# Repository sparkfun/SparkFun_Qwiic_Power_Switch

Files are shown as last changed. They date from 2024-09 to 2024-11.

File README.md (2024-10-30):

SparkFun Qwiic Power Switch
========================================

A power switch for your Qwiic system.

SparkFun Qwiic Power Switch (PRT-26784) (https://www.sparkfun.com/products/26784)

[SparkFun Qwiic Power Switch (PRT-26784)](https://www.sparkfun.com/products/26784)

The Qwiic Power Switch is a simple little board which can be used to switch the power to your Qwiic
system. Many Qwiic boards draw very little current when not being used, but there are some that draw
significantly more. The power switch allows you to switch the power to those boards, so you can minimize the
current draw and extend your battery life when you need to.

When the Qwiic Power Switch is turned off, the I2C wires are isolated too which prevents the pull-up
resistors from feeding parasitic power to your Qwiic boards. The power switch can also be used to
isolate a 400kHz bus from a 100kHz bus; the slower bus can be disconnected during fast-mode communication
without disabling the power.

The heart of the Qwiic Power Switch is the TI PCA9536 4-Bit I2C I/O Expander. We have broken out GPIO pins
1 and 2 so you can use them as general purpose inputs or outputs.

Repository Contents
-------------------

* **.github/workflows** - YAML files used for GitHub Actions and GitHub Pages/mkdocs
* **/Hardware** - Eagle design files (.brd, .sch)
  * **/Production** - Production panel files (.brd)
* **/docs** - Online documentation files
  * **/assets** - Folder containing all the file assets used for product documentation
    * **/board_files** - Copy of design files used for product documentation
    * **/component_documentation** - Datasheets and manuals for hardware components
    * **/img** - Images for product documentation
  * **/github** - Files stating how to contribute and filing issues used for product documentation
  * **/javascript** - Folder containing custom javascript used for product documentation
  * **/stylesheet** - Folder containing CSS files used for product documentation
* **/overrides** - Customization files used for product documentation
  * **/.icons** - Icons used for GitHub used for product documentation
  * **./partials** - Used for product documentation
* **LICENSE.md** contains the licence information

Documentation
-------------------

* **[Installing an Arduino Library Guide](https://learn.sparkfun.com/tutorials/installing-an-arduino-library)** - Basic information on how to install an Arduino library.
* **[Arduino Library](https://github.com/sparkfun/SparkFun_Qwiic_Power_Switch_Arduino_Library)** - Library for the Qwiic Power Switch
* **[Hookup Guide](https://docs.sparkfun.com/SparkFun_Qwiic_Power_Switch/introduction/)** - Basic hookup guide for the Qwiic Power Switch.

Product Versions
----------------

* [PRT-26784](https://www.sparkfun.com/products/26784) - SparkFun Red Version
* [SPX-16740](https://www.sparkfun.com/products/16740) - SparkX Version

License Information
-------------------

This product is _**open source**_!

Please review the LICENSE.md file for license information.

If you have any questions or concerns on licensing, please contact technical support on our [SparkFun forums](https://forum.sparkfun.com/viewforum.php?f=123).

Distributed as-is; no warranty is given.

- Your friends at SparkFun.

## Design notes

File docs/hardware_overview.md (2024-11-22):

In this section, we will highlight the hardware and pins that are broken out on the SparkFun Qwiic Power Switch. For more information, check out our [Resources and Going Further](../resources/) on the components used on the breakout board.

<div style="text-align: center;">
  <table>
    <tr style="vertical-align:middle;">
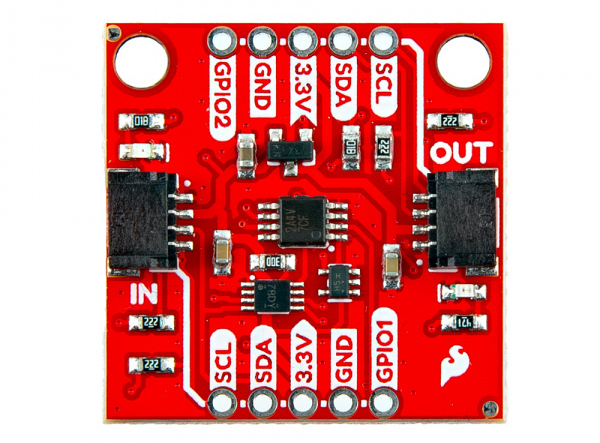
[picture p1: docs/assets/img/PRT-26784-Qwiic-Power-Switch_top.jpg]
Top View
     <td style="text-align: center; vertical-align: middle; border: solid 1px #cccccc;"></td>
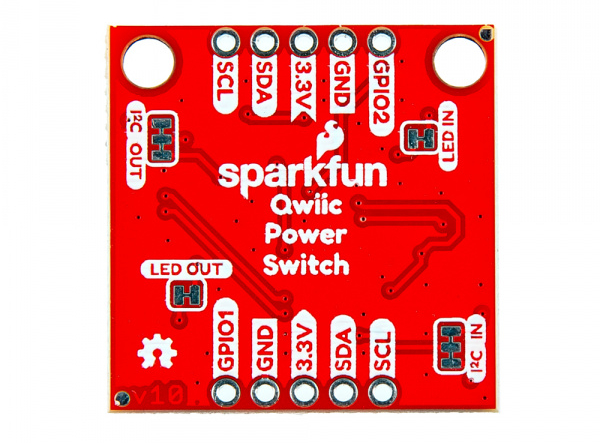
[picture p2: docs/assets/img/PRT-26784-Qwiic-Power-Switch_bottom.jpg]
Bottom View
     <td style="text-align: center; vertical-align: middle; border: solid 1px #cccccc;"></td>
    </tr>
    <tr style="vertical-align:middle;">
     <td style="text-align: center; vertical-align: middle; border: solid 1px #cccccc;"><i>Top View</i></td>
     <td style="text-align: center; vertical-align: middle; border: solid 1px #cccccc;"><i>Bottom View</i></td>
    </tr>
  </table>
</div>

### Power

To power the board, we recommend applying 3.3V to the 3.3V pin on the side labeled IN. While the IC's operating voltage is 2.3V to 5.5V, we recommend limiting the input voltage to 3.3V for the Qwiic Connect System. Below are the power pins that are broken out on the edge of the board.

* **IN - 3.3V** &mdash; This pin is the voltage input for the board. The recommended input voltage for this pin is 3.3V.
* **OUT - 3.3V** &mdash; This pin is the voltage output for the board. When the PCA9536 GPIO0 enables the transistor, any Qwiic enabled device that is connected to this side of the board will be powered by 3.3V.
* **GND** &mdash; Of course, is the common, ground voltage (0V reference) for the system.

<div style="text-align: center;">
  <table>
    <tr style="vertical-align:middle;">
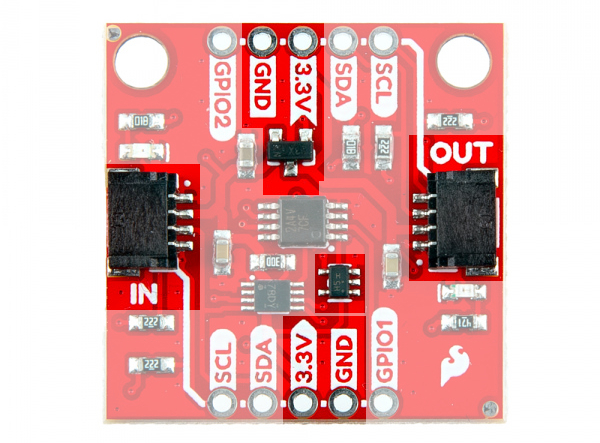
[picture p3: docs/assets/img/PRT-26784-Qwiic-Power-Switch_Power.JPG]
Power, Ground, Transistor and Qwiic Connector Highlighted
     <td style="text-align: center; vertical-align: middle; border: solid 1px #cccccc;"></td>
    </tr>
    <tr style="vertical-align:middle;">
     <td style="text-align: center; vertical-align: middle; border: solid 1px #cccccc;"><i>Power, Ground, Transistor, and Qwiic Connector Highlighted</i></td>
    </tr>
  </table>
</div>

### Qwiic and I<sup>2</sup>C

The board includes two horizontal Qwiic connectors to connect Qwiic-enabled I<sup>2</sup>C devices. However, the board still breaks out 0.1"-spaced pins for users who prefer a soldered connection. The PCA9306 dual bidirectional I<sup>2</sup>C bus voltage level translator (the 8-pin IC closer to IN by the SDA and 3.3V PTHs) is included between the input and output Qwiic connectors. This acts as a bus isolator between the input and output pins for the data and clock lines. This prevents the pull-up resistors from feeding parasitic power to your Qwiic-enabled boards. The Qwiic Power Switch can also be used to isolate a 400kHz bus from a 100kHz bus; the slower bus on the output of the Qwiic Power Switch can be disconnected during fast-mode communication without disabling power.

* **IN**
    * **SCL** &mdash; I<sup>2</sup>C clock on the PCA9306&apos;s input side.
    * **SDA** &mdash; I<sup>2</sup>C data on the PCA9306&apos;s input side.
    * **3.3V** &mdash; This pin is the voltage input for the board. The recommended input voltage for this pin is 3.3V.
* **OUT**
    * **SCL** &mdash; I<sup>2</sup>C clock on the PCA9306&apos;s output side.
    * **SDA** &mdash; I<sup>2</sup>C data on the PCA9306&apos;s output side.
    * **3.3V** &mdash; This pin is the voltage output for the board. When the PCA9536 GPIO0 enables the transistor, any Qwiic enabled device that is connected to this side of the board will be powered by 3.3V.
* **GND** &mdash; Of course, is the common, ground voltage (0V reference) for the system. The GND PTHs are connected to both IN and OUT.

<div style="text-align: center;">
  <table>
    <tr style="vertical-align:middle;">
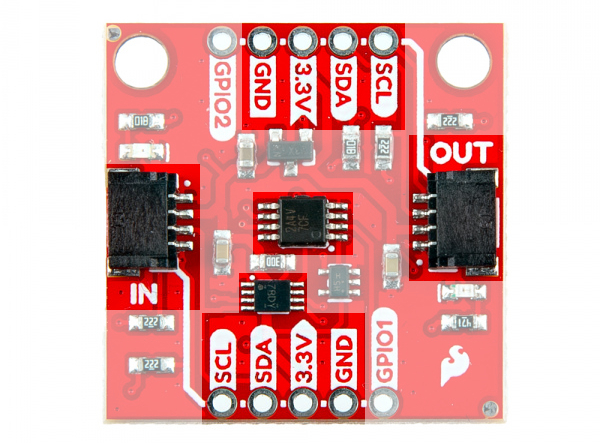
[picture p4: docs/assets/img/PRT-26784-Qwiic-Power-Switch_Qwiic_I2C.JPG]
Qwiic Connector, I2C, and PCA9306 Highlighted
     <td style="text-align: center; vertical-align: middle; border: solid 1px #cccccc;"></td>
    </tr>
    <tr style="vertical-align:middle;">
     <td style="text-align: center; vertical-align: middle; border: solid 1px #cccccc;"><i>Qwiic Connector, I<sup>2</sup>C, and PCA9306 Highlighted</i></td>
    </tr>
  </table>
</div>

Connected on the input I<sup>2</sup>C bus is the TI PCA9536 4-Bit I<sup>2</sup>C I/O Expander (the bigger 8-pin IC located at the center of the board). This IC is used to toggle output 3.3V power and the PCA9306 I<sup>2</sup>C isolation. Its I<sup>2</sup>C device's 7-bit unshifted address is **0x41**.

### PCA9536 and GPIO Pins

The PCA9536 is a 4-bit GPIO IC that enables users to toggle the following GPIO pins through I<sup>2</sup>C. The I<sup>2</sup>C address of the PCA9536 is **0x41**.

* **GPIO0** &mdash; GPIO0 is connected to the MOSFET power switch. This controls the voltage between the 3.3V input pin and VOUT. When this transistor is turned off, power is removed from the I<sup>2</sup>C output's pull-up resistors.
* **GPIO1** &mdash; GPIO1 is an extra GPIO pin.
* **GPIO2** &mdash; GPIO2 is an extra GPIO pin.
* **GPIO3** &mdash; This pin is connected to the PCA9306. This allows you to isolate the I<sup>2</sup>C output.

<div style="text-align: center;">
  <table>
    <tr style="vertical-align:middle;">
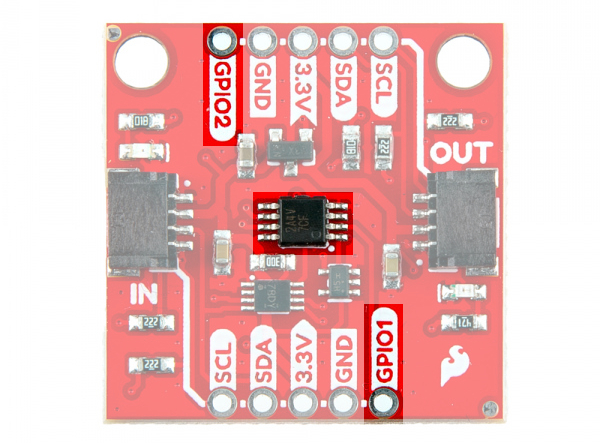
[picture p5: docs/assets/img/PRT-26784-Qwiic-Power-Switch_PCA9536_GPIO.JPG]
PCA9536 and GPIO Pins Highlighted
     <td style="text-align: center; vertical-align: middle; border: solid 1px #cccccc;"></td>
    </tr>
    <tr style="vertical-align:middle;">
     <td style="text-align: center; vertical-align: middle; border: solid 1px #cccccc;"><i>PCA9536 and GPIO Pins Highlighted</i></td>
    </tr>
  </table>
</div>

### LEDs

The board includes two LEDs to indicate when power is available on the input and output's 3.3V pins. Both can be disabled with the jumpers on the back of the board.

<div style="text-align: center;">
  <table>
    <tr style="vertical-align:middle;">
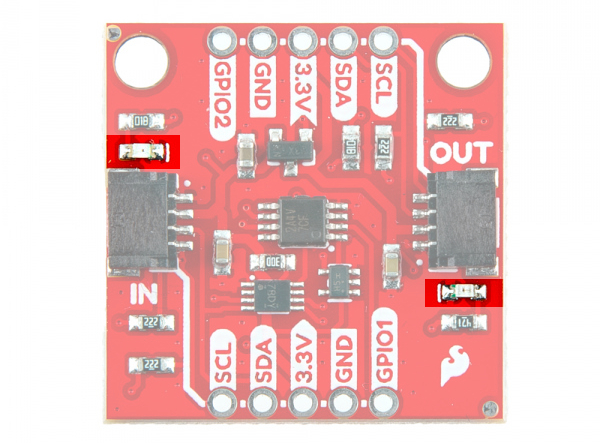
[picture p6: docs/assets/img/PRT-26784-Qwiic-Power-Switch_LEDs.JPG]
LEDs Highlighted
     <td style="text-align: center; vertical-align: middle; border: solid 1px #cccccc;"></td>
    </tr>
    <tr style="vertical-align:middle;">
     <td style="text-align: center; vertical-align: middle; border: solid 1px #cccccc;"><i>LEDs Highlighted</i></td>
    </tr>
  </table>
</div>

### Jumpers

!!!note
    If this is your first time working with jumpers, check out the [How to Work with Jumper Pads and PCB Traces](https://learn.sparkfun.com/tutorials/how-to-work-with-jumper-pads-and-pcb-traces/all) tutorial for more information.

The back of the board includes jumpers to configure the board.

* **I<sup>2</sup>C IN** &mdash; By default, this three-pad jumper is closed. The three way jumper labeled I<sup>2</sup>C IN connects 3.3V to two 2.2k&ohm; pull-up resistors and to the I<sup>2</sup>C data and clock lines. If multiple devices are connected to the bus with the pull-up resistors enabled, the parallel equivalent resistance will create too strong of a pull-up for the bus to operate correctly. As a general rule of thumb, [disable all but one pair of pull-up resistors](https://learn.sparkfun.com/tutorials/i2c/all#i2c-at-the-hardware-level) if multiple devices are connected to the bus.
* **I<sup>2</sup>C OUT** &mdash; By default, this three-pad jumper is closed. Similar to the I<sup>2</sup>C IN jumper, this jumper is connects the VOUT net to two 2.2k&ohm; pull-up resistors and to the I<sup>2</sup>C data and clock lines. This VOUT is controlled by a MOSFET power switch and PCA9536's GPIO0. When the transistor is turned on, VOUT will connect to the input 3.3V pin.
* **LED IN** &mdash; By default, this jumper connects the LED to the input's 3.3V pin. Cutting this trace disables the LED.
* **LED OUT** &mdash; By default, this jumper connects the LED to the output's 3.3V pin. Cutting this trace disables the LED.

<div style="text-align: center;">
  <table>
    <tr style="vertical-align:middle;">
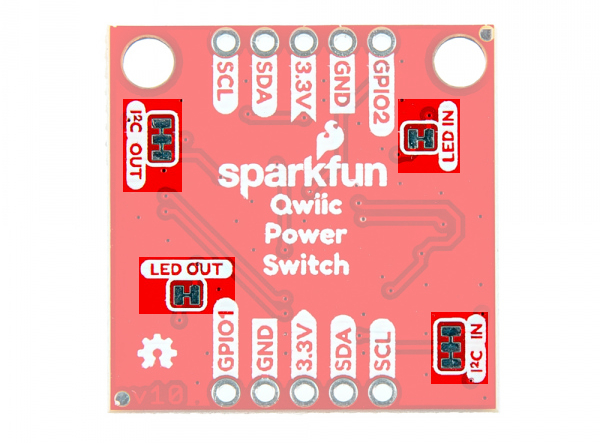
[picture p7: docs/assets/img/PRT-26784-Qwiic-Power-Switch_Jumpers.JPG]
Jumpers Highlighted
     <td style="text-align: center; vertical-align: middle; border: solid 1px #cccccc;"></td>
    </tr>
    <tr style="vertical-align:middle;">
     <td style="text-align: center; vertical-align: middle; border: solid 1px #cccccc;"><i>Jumpers Highlighted</i></td>
    </tr>
  </table>
</div>

### Board Dimensions

The board is 1.0" x 1.0" (25.4mm x 25.4mm). There are 2x mounting holes. You can use 4-40 standoffs to mount the board to a panel or enclosure.

<div style="text-align: center;">
  <table>
    <tr style="vertical-align:middle;">
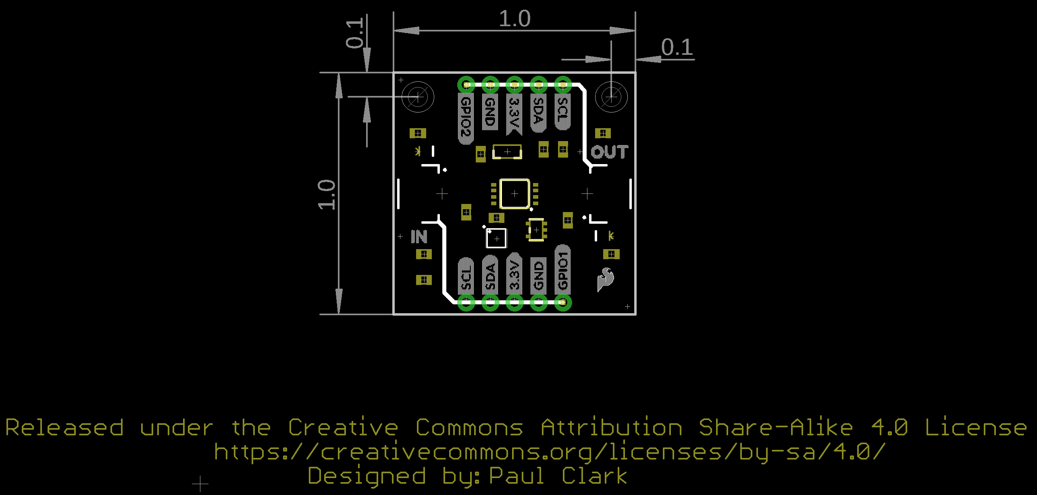
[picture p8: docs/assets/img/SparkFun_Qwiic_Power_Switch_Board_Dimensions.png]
Board Dimensions
     <td style="text-align: center; vertical-align: middle; border: solid 1px #cccccc;"></td>
    </tr>
    <tr style="vertical-align:middle;">
     <td style="text-align: center; vertical-align: middle; border: solid 1px #cccccc;"><i>Board Dimensions</i></td>
    </tr>
  </table>
</div>

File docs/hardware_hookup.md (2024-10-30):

In this section, we will go over how to connect to the Qwiic Power Switch.

### Connecting Via Qwiic

Insert a Qwiic cable between your Arduino microcontroller and the Qwiic Power Switch&apos;s IN port. In this case, we used the SparkFun Thing Plus ESP32- USB-C for the Arduino microcontroller. Then connect Qwiic cable between the Qwiic Power Switch's OUT port to the second Qwiic-enabled device. In this case, we used the ZED-F9P SMA breakout board when toggling power and isolating the I<sup>2</sup>C lines. We also connected an external multiband antenna to the ZED-F9P. When ready, connect a USB cable to the Arduino to program, power, and control the Qwiic Power Switch through a serial terminal.

<div style="text-align: center;">
  <table>
    <tr style="vertical-align:middle;">
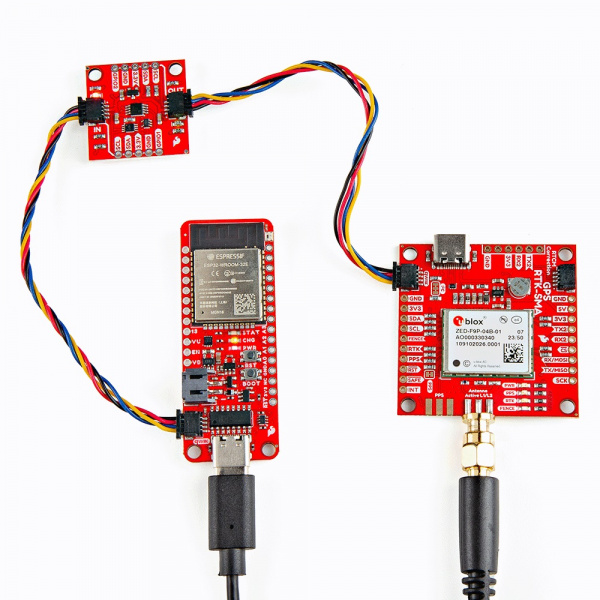
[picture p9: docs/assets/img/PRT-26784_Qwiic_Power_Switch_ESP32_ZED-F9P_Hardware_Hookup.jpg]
Thing Plus ESP32, Qwiic Power Switch, ZED-F9P Connected via Qwiic
     <td style="text-align: center; vertical-align: middle; border: solid 1px #cccccc;"></td>
    </tr>
    <tr style="vertical-align:middle;">
     <td style="text-align: center; vertical-align: middle; border: solid 1px #cccccc;"><i>Thing Plus ESP32, Qwiic Power Switch, ZED-F9P Connected via Qwiic</i></td>
    </tr>
  </table>
</div>

!!! note
    To isolate any Qwiic-enabled device, you will need to connect the Qwiic-enabled device from the OUT port.

### Connecting via PTH

For temporary connections to the PTHs, you could use IC hooks to test out the pins. However, you'll need to solder headers or wires of your choice to the board for a secure connection. You can choose between a combination of [header pins and jumper wires](https://learn.sparkfun.com/tutorials/how-to-solder-through-hole-soldering/all), or [stripping wire and soldering the wire](https://learn.sparkfun.com/tutorials/working-with-wire/all) directly to the board.

<div class="grid cards col-2" markdown>

-   <a href="https://learn.sparkfun.com/tutorials/how-to-solder-through-hole-soldering/all">
      <figure markdown>
        How to Solder: Through Hole Soldering
      </figure>
    </a>

    ---

    <a href="https://learn.sparkfun.com/tutorials/how-to-solder-through-hole-soldering/all">
      <b>How to Solder: Through Hole Soldering</b>
    </a>
<!-- ----------WHITE SPACE BETWEEN GRID CARDS---------- -->

-   <a href="https://learn.sparkfun.com/tutorials/working-with-wire/all">
      <figure markdown>
        Working with Wire
      </figure>
    </a>

    ---

    <a href="https://learn.sparkfun.com/tutorials/working-with-wire/all">
      <b>Working with Wire</b>
    </a>
<!-- ----------WHITE SPACE BETWEEN GRID CARDS---------- -->
</div>

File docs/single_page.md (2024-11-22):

---
hide:
  - navigation
  - toc
icon: fontawesome/solid/scroll
---

# Introduction
--8<-- "./docs/introduction.md"

# Hardware Overview
--8<-- "./docs/hardware_overview.md"

# Hardware Hookup
--8<-- "./docs/hardware_hookup.md"

# Setting Up Arduino
--8<-- "./docs/arduino_library.md"

# Arduino Example
--8<-- "./docs/arduino_example.md"

# Troubleshooting
--8<-- "./docs/troubleshooting.md"

# Resources
--8<-- "./docs/resources.md"

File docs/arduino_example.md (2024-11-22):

Now that we have our library and board add-on installed, we can start experimenting with the breakout board. For the scope of this tutorial, we will highlight the example in the Arduino Library to get started.

### Upload Arduino Example

After unzipping the compressed files, navigate to the example: **File** > **Examples** > **SparkFun Qwiic Power Switch Arduino Library** > **Example1_PowerOnOff**. This example allows you to toggle power and isolate the I<sup>2</sup>C lines for the OUT port through a serial terminal. The example also allows you to read GPIO1 and GPIO2.

For users using an Arduino microcontroller, select your board in the Tools menu (in our case the **SparkFun ESP32 Thing Plus C**) and the correct Port it enumerated on.

You can also copy or paste the code as shown below. Then click "Upload".

``` c++
    /*
      Using the Qwiic Power Switch
      By: Paul Clark (PaulZC)
      Date: April 23rd, 2020

      Based extensively on:
      Using the PCA9536 -- Digital Output
      By: Jim Lindblom
      SparkFun Electronics
      Date: May 4, 2018

      License: This code is public domain but you buy me a beer if you use this and we meet someday (Beerware license).

      This example demonstrates how to use the Qwiic Power Switch and read the additional GPIO pins

      Hardware Connections:
      Attach your Arduino to the Qwiic Power Switch IN
      Plug your Qwiic device into the Qwiic Power Switch OUT
      https://www.sparkfun.com/products/15081
    */

    #include <Wire.h>

    #include <SparkFun_Qwiic_Power_Switch_Arduino_Library.h>

    QWIIC_POWER mySwitch;

    void setup(void)
    {
      Serial.begin(115200);
      while (!Serial)
        ; //Wait for user to open terminal
      Serial.println(F("Qwiic Power Switch Example"));

      Wire.begin();

      if (mySwitch.begin() == false) //Connect to the power switch using Wire port
      {
        Serial.println(F("Qwiic Power Switch not detected at default I2C address. Please check wiring. Freezing."));
        while (1)
          ;
      }

      // Configure GPIO1 and GPIO2 as INPUT
      mySwitch.pinMode(1, INPUT);
      mySwitch.pinMode(2, INPUT);

      Serial.println(F("1) Enable power and I2C"));
      Serial.println(F("2) Disable power and I2C"));
      Serial.println(F("3) Enable I2C isolation"));
      Serial.println(F("4) Disable I2C isolation"));
    }

    void loop()
    {
      if (Serial.available())
      {
        byte incoming = Serial.read();

        if (incoming == '1')
        {
          // Switch the power on
          mySwitch.powerOn();
          Serial.println(F("Power is ON. I2C isolation is disabled."));
        }
        else if (incoming == '2')
        {
          // Switch the power off
          mySwitch.powerOff();
          Serial.println(F("Power is OFF. I2C isolation is enabled."));
        }
        else if (incoming == '3')
        {
          // Enable I2C isolation = I2C bus _is_ isolated
          mySwitch.isolationOn();
          Serial.println(F("I2C isolation enabled. I2C is isolated."));
        }
        else if (incoming == '4')
        {
          // Disable I2C isolation = I2C bus _is not_ isolated
          mySwitch.isolationOff();
          Serial.println(F("I2C isolation disabled. I2C is not isolated."));
        }

        // Read and print the GPIO1/GPIO2 state
        Serial.print(F("GPIO1 is: "));
        Serial.println(mySwitch.digitalRead(1));
        Serial.print(F("GPIO2 is: "));
        Serial.println(mySwitch.digitalRead(2));

        // Read any extra Serial bytes (e.g. CR or LF)
        while (Serial.available() > 0)
        {
          Serial.read();
        }
      }
    }

```

!!! tip
    Instead of reading GPIO1 and GPIO2, you can write to the GPIO pins to set the pins HIGH or LOW. You will need to change the following lines of code in the `setup()` and `loop()` functions where the GPIO1 and GPIO2 are initialized and read.

    ``` c++
    setup(){
      .
      .
      .
      // Configure GPIO1 and GPIO2 as INPUT
      mySwitch.pinMode(1, INPUT);
      mySwitch.pinMode(2, INPUT);
      .
      .
      .
    }

    void loop() {
          .
          .
          .
          // Read and print the GPIO1/GPIO2 state
          Serial.print(F("GPIO1 is: "));
          Serial.println(mySwitch.digitalRead(1));
          Serial.print(F("GPIO2 is: "));
          Serial.println(mySwitch.digitalRead(2));
          .
          .
          .
    }
    ```

    Instead of an INPUT, you will change each GPIO pin as an OUTPUT. Additionally, you will need to set the pin as a HIGH or LOW.

    ``` c++
    setup(){
      .
      .
      .
      // Configure GPIO1 and GPIO2 as OUTPUT
      mySwitch.pinMode(1, OUTPUT);
      mySwitch.pinMode(2, OUTPUT);
      .
      .
      .
    }

    void loop() {
          .
          .
          .
          // Write to GPIO1 & GPIO2
          Serial.println(F("GPIO1 is set to HIGH."));
          mySwitch.digitalWrite(1, HIGH);
          Serial.println(F("GPIO2 is set to LOW."));
          mySwitch.digitalWrite(2, LOW);
          .
          .
          .
    }
    ```

    To test, simply attach an LED with a current limiting resistor between the GPIO and GND. The LED should light up when the pin is HIGH and turn off when set to LOW. Of course, you can also connect a multimeter set to read the voltage between the GPIO pin nd GND. The GPIO pin should read 3.3V when set to HIGH and 0V when set to LOW.

After uploading the code, open the [Serial Monitor](https://learn.sparkfun.com/tutorials/terminal-basics) or terminal emulator of your choice with the baud rate set to **115200**. You will be presented with a few options to configure the Qwiic Power Switch:

* <kbd>1</kbd> &mdash; Power is ON I2C isolation is disabled.
* <kbd>2</kbd> &mdash; Power is OFF. I2C isolation is enabled.
* <kbd>3</kbd> &mdash; I2C isolation enabled. I2C is isolated.
* <kbd>4</kbd> &mdash; I2C isolation disabled. I2C is not isolated.

<div style="text-align: center;">
  <table>
    <tr style="vertical-align:middle;">
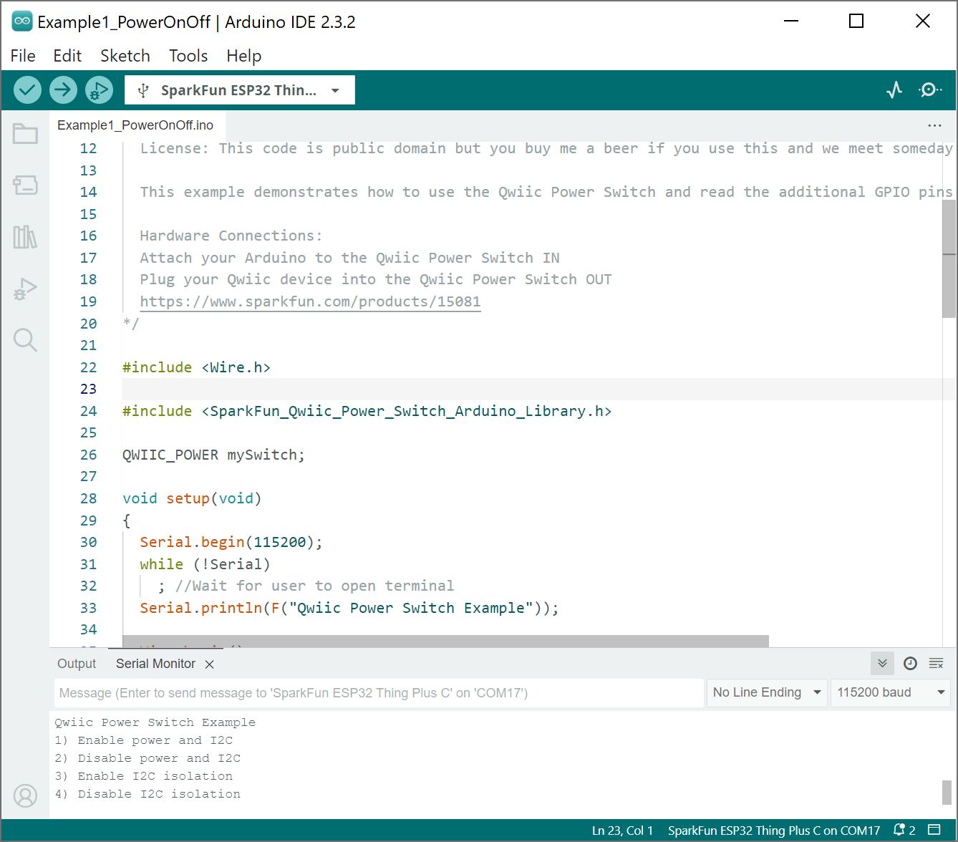
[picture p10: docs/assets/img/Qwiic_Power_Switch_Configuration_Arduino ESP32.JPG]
Qwiic Power Switch Configuration with Arduino ESP32
     <td style="text-align: center; vertical-align: middle; border: solid 1px #cccccc;"></td>
    </tr>
    <tr style="vertical-align:middle;">
     <td style="text-align: center; vertical-align: middle; border: solid 1px #cccccc;"><i>Qwiic Power Switch Configuration with Arduino ESP32</i></td>
    </tr>
  </table>
</div>

Let&apos;s send a <kbd>2</kbd> to turn power off the Qwiic Power Switch&apos;s output and isolate the I<sup>2</sup>C data and clock lines. The Arduino will output a message: "Power is OFF. I2C isolation is enabled." The Arduino will also read the Qwiic Power Switch's GPIO1 and GPIO2. In this case, there was nothing connected to either GPIO so the pin reading was `1` indicating a HIGH. If there was a logic LOW, the pin would read `0` indicating a LOW.

<div style="text-align: center;">
  <table>
    <tr style="vertical-align:middle;">
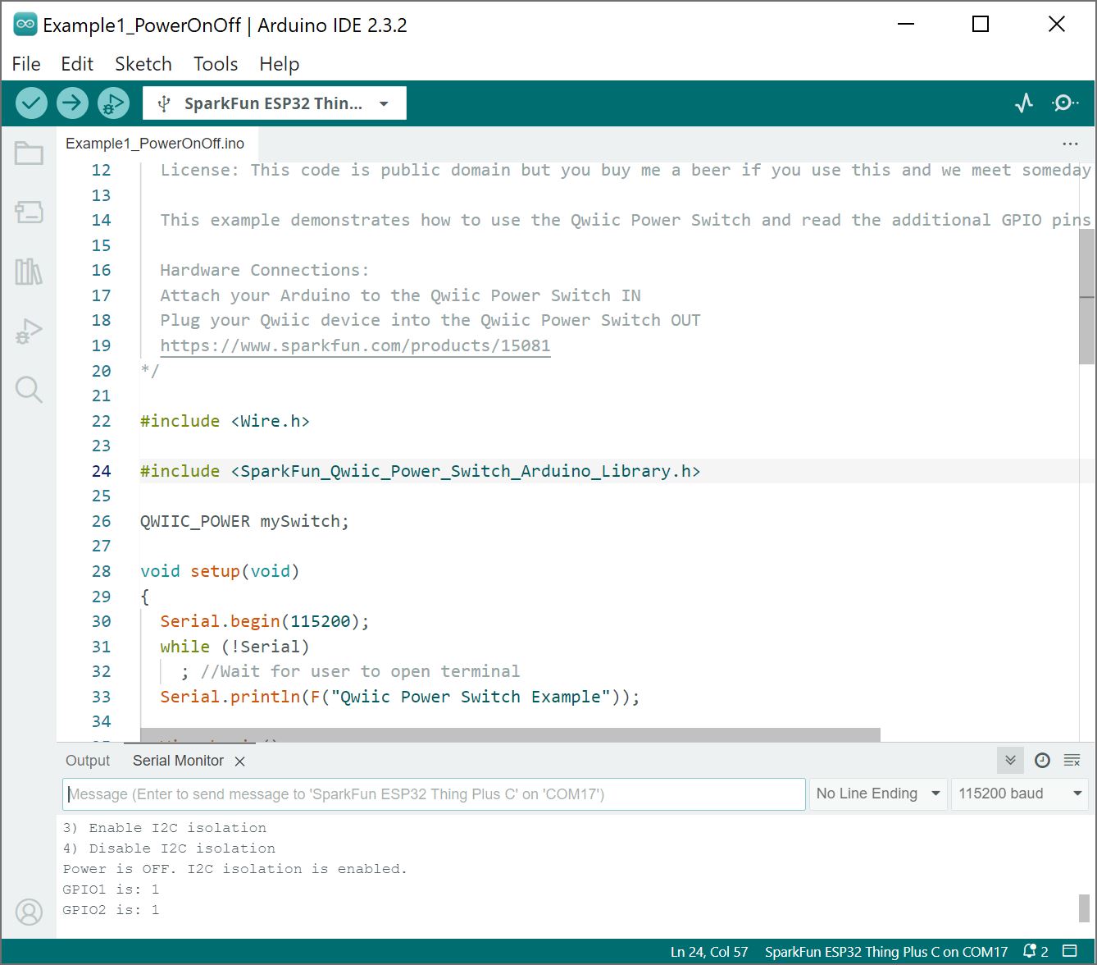
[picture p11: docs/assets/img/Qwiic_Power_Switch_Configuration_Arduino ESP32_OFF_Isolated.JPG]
Qwiic Power Switch Output OFF, I2C Isolated, and GPIO Readings with Arduino ESP32
     <td style="text-align: center; vertical-align: middle; border: solid 1px #cccccc;"></td>
    </tr>
    <tr style="vertical-align:middle;">
     <td style="text-align: center; vertical-align: middle; border: solid 1px #cccccc;"><i>Qwiic Power Switch Output OFF, I<sup>2</sup>C Isolated, and GPIO Readings with Arduino ESP32</i></td>
    </tr>
  </table>
</div>

If the Qwiic-enabled board includes a built-in LED, you can see if power is enabled. The power LED (as well as any other LED on the board) should have turned off as soon as power is disabled at the OUT port. In this case, the Qwiic Power Switch's OUT and ZED-F9P's LEDs when power was disabled and I<sup>2</sup>C isolation is enabled.

<div style="text-align: center;">
  <table>
    <tr style="vertical-align:middle;">
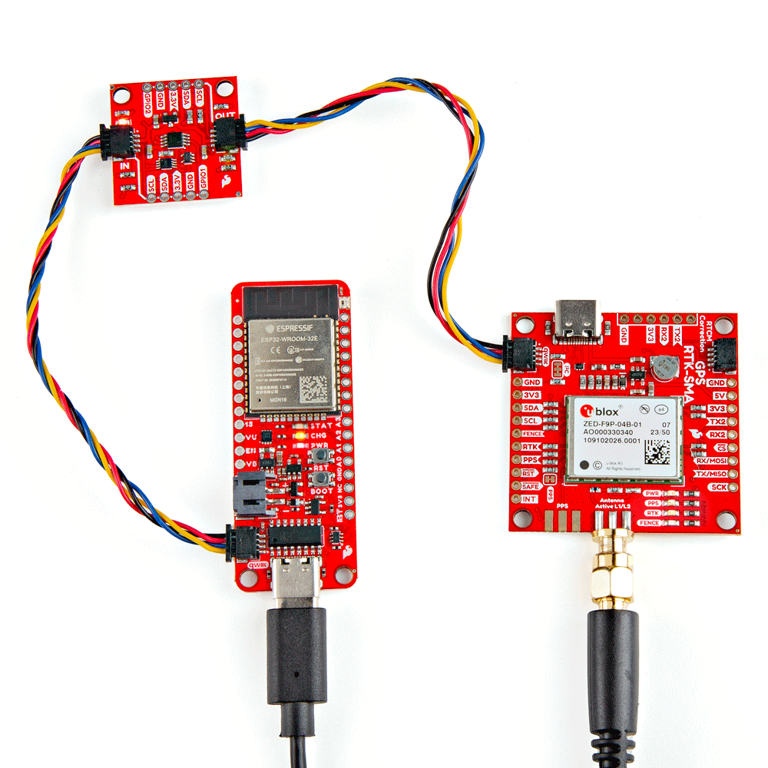
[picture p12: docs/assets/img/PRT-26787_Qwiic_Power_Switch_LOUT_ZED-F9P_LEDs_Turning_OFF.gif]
Qwiic Power Switch OUT and ZED-F9P LEDs Turning OFF
     <td style="text-align: center; vertical-align: middle; border: solid 1px #cccccc;"></td>
    </tr>
    <tr style="vertical-align:middle;">
     <td style="text-align: center; vertical-align: middle; border: solid 1px #cccccc;"><i>Qwiic Power Switch OUT and ZED-F9P LEDs Turning OFF</i></td>
    </tr>
  </table>
</div>

!!! note
    If power is OFF at the OUT port but you decide to disable I<sup>2</sup>C isolation, you may notice a voltage at the 3.3V OUT pin from the pull-up resistors connected to the I<sup>2</sup>C lines.

If you would like to verify that the I<sup>2</sup>C lines are isolated, try turning the power back on by sending a <kbd>1</kbd> and then sending a <kbd>3</kbd> to isolate the I<sup>2</sup>C lines. While still applying power to the Qwiic Power Switch, try re-uploading code to the Arduino for the Qwiic-enabled board that is connected to the Qwiic Power Switch's OUT. Assuming that the example code checks for the Qwiic-enabled device, you should receive a message indicating that the Qwiic-enabled device was not detected.

!!! note
    Of course, you could also use the [Arduino I2C scanner](https://playground.arduino.cc/Main/I2cScanner/) to scan the I<sup>2</sup>C bus and detect I<sup>2</sup>C devices. When scanning, you should only see the Qwwic Power Switch and anything that was connected before the IN port. Anything after the OUT will not be detected on the OUT port if power was disabled or the lines were isolated.

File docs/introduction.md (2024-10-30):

Many of our Qwiic products draw very little current when in standby, but there are some that draw considerably more. Products like our top-end [u-blox GNSS boards](https://www.sparkfun.com/products/16481) in particular. There are times when you wish you could switch them off to save power, and the [SparkFun Qwiic Power Switch (QPS)](https://www.sparkfun.com/products/26784) allows you to do exactly that!

<div class="grid cards" style="width:500px; margin: 0 auto;" markdown>

-   <a href="https://www.sparkfun.com/products/26784">
      <figure markdown>
        SparkFun Qwiic Power Switch
      </figure>
    </a>

    ---

    <a href="https://www.sparkfun.com/products/26784">
      <b>SparkFun Qwiic Power Switch</b>
      <br />
      PRT-26784
      <br />
      <center>[Purchase from SparkFun :fontawesome-solid-cart-plus:](https://www.sparkfun.com/products/26784){ .md-button .md-button--primary }</center>
    </a>
</div>

In this tutorial, we'll go over the hardware and how to hookup the SparkFun Qwiic Power Switch to an Arduino. We will also go over an Arduino example to get started.

### Required Materials

To follow along with this tutorial, you will need the following materials. You may not need everything though depending on what you have. Add it to your cart, read through the guide, and adjust the cart as necessary.

<div class="grid cards col-4" markdown>

<!-- ----------WHITE SPACE BETWEEN PRODUCTS---------- -->
-   <a href="https://www.sparkfun.com/products/15424">
      <figure markdown>
        Reversible USB A to C Cable - 2m
      </figure>
    </a>

    ---

    <a href="https://www.sparkfun.com/products/15424">
      <b>Reversible USB A to C Cable - 2m</b>
      <br />
      CAB-15424
    </a>
<!-- ----------WHITE SPACE BETWEEN PRODUCTS---------- -->
-   <a href="https://www.sparkfun.com/products/20168">
      <figure markdown>
        SparkFun Thing Plus - ESP32 WROOM (USB-C)
      </figure>
    </a>

    ---

    <a href="https://www.sparkfun.com/products/20168">
      <b>SparkFun Thing Plus - ESP32 WROOM (USB-C)</b>
      <br />
      WRL-20168
    </a>
<!-- ----------WHITE SPACE BETWEEN PRODUCTS---------- -->
-   <a href="https://www.sparkfun.com/products/26784">
      <figure markdown>
        SparkFun Qwiic Power Switch
      </figure>
    </a>

    ---

    <a href="https://www.sparkfun.com/products/26784">
      <b>SparkFun Qwiic Power Switch</b>
      <br />
      PRT-26784
    </a>
<!-- ----------WHITE SPACE BETWEEN PRODUCTS---------- -->
-   <a href="https://www.sparkfun.com/products/14427">
      <figure markdown>
        Qwiic Cable - 100mm
      </figure>
    </a>

    ---

    <a href="https://www.sparkfun.com/products/14427">
      <b>Qwiic Cable - 100mm</b>
      <br>
      PRT-14427
    </a>
<!-- ----------WHITE SPACE BETWEEN PRODUCTS---------- -->
</div>

You will also need a Qwiic-enabled device and an additional Qwiic cable. In this case, we used a ZED-F9P for demonstration purposes. Of course, you could use a different Qwiic-enabled device.

<div class="grid cards col-4" markdown>
<!-- ----------WHITE SPACE BETWEEN PRODUCTS---------- -->
-   <a href="https://www.sparkfun.com/products/16481">
      <figure markdown>
        SparkFun GPS-RTK-SMA Breakout - ZED-F9P (Qwiic)
      </figure>
    </a>

    ---

    <a href="https://www.sparkfun.com/products/16481">
      <b>SparkFun GPS-RTK-SMA Breakout - ZED-F9P (Qwiic)</b>
      <br />
      GPS-16481
    </a>
<!-- ----------WHITE SPACE BETWEEN PRODUCTS---------- -->
-   <a href="https://www.sparkfun.com/products/15192">
      <figure markdown>
        GNSS L1/L2 Multi-Band Magnetic Mount Antenna - 5m (SMA)
      </figure>
    </a>

    ---

    <a href="https://www.sparkfun.com/products/15192">
      <b>GNSS L1/L2 Multi-Band Magnetic Mount Antenna - 5m (SMA)</b>
      <br />
      GPS-15192
    </a>
<!-- ----------WHITE SPACE BETWEEN PRODUCTS---------- -->
-   <a href="https://www.sparkfun.com/products/14429">
      <figure markdown>
        Qwiic Cable - 500mm
      </figure>
    </a>

    ---

    <a href="https://www.sparkfun.com/products/14429">
      <b>Qwiic Cable - 500mm</b>
      <br />
      PRT-14429
    </a>
<!-- ----------WHITE SPACE BETWEEN PRODUCTS---------- -->
</div>

### Qwiic Cables

For those that want to take advantage of the Qwiic connector, you'll want to grab a Qwiic cable. There are a variety of other cable lengths available in the SparkFun catalog to choose from.

<div class="grid cards col-4" markdown>

-   <a href="https://www.sparkfun.com/products/15081">
      <figure markdown>
        SparkFun Qwiic Cable Kit
      </figure>
    </a>

    ---

    <a href="https://www.sparkfun.com/products/15081">
      <b>SparkFun Qwiic Cable Kit</b>
      <br />
      KIT-15081
    </a>
<!-- ----------WHITE SPACE BETWEEN PRODUCTS---------- -->
-   <a href="https://www.sparkfun.com/products/14427">
      <figure markdown>
        Qwiic Cable - 100mm
      </figure>
    </a>

    ---

    <a href="https://www.sparkfun.com/products/14427">
      <b>Qwiic Cable - 100mm</b>
      <br>
      PRT-14427
    </a>
<!-- ----------WHITE SPACE BETWEEN PRODUCTS---------- -->
-   <a href="https://www.sparkfun.com/products/14429">
      <figure markdown>
        Qwiic Cable - 500mm
      </figure>
    </a>

    ---

    <a href="https://www.sparkfun.com/products/14429">
      <b>Qwiic Cable - 500mm</b>
      <br />
      PRT-14429
    </a>
<!-- ----------WHITE SPACE BETWEEN PRODUCTS---------- -->
-   <a href="https://www.sparkfun.com/products/14425">
      <figure markdown>
        Qwiic Cable - Breadboard Jumper (4-pin)
      </figure>
    </a>

    ---

    <a href="https://www.sparkfun.com/products/14425">
      <b>Qwiic Cable - Breadboard Jumper (4-pin)</b>
      <br />
      PRT-14425
    </a>
<!-- ----------WHITE SPACE BETWEEN PRODUCTS---------- -->
</div>

### Tools _(Optional)_

For users connecting to the plated through holes, you will need a soldering iron, solder, and [general soldering accessories](https://www.sparkfun.com/categories/49).

<div class="grid cards col-4" markdown>

-   <a href="https://www.sparkfun.com/products/24063">
      <figure markdown>
        PINECIL Soldering Iron Kit
      </figure>
    </a>

    ---

    <a href="https://www.sparkfun.com/products/24063">
      <b>PINECIL Soldering Iron Kit</b>
      <br />
      TOL-24063
    </a>
<!-- ----------WHITE SPACE BETWEEN PRODUCTS---------- -->
-   <a href="https://www.sparkfun.com/products/9163">
      <figure markdown>
        Solder Lead Free - 15-gram Tube
      </figure>
    </a>

    ---

    <a href="https://www.sparkfun.com/products/9163">
      <b>Solder Lead Free - 15-gram Tube</b>
      <br>
      TOL-09163
    </a>
<!-- ----------WHITE SPACE BETWEEN PRODUCTS---------- -->
-   <a href="https://www.sparkfun.com/products/11375">
      <figure markdown>
        Hook-Up Wire - Assortment (Stranded, 22 AWG)
      </figure>
    </a>

    ---

    <a href="https://www.sparkfun.com/products/11375">
      <b>Hook-Up Wire - Assortment (Stranded, 22 AWG)</b>
      <br />
      PRT-11375
    </a>
<!-- ----------WHITE SPACE BETWEEN PRODUCTS---------- -->
-   <a href="https://www.sparkfun.com/products/12630">
      <figure markdown>
        Wire Strippers - 30AWG (Hakko)
      </figure>
    </a>

    ---

    <a href="https://www.sparkfun.com/products/12630">
      <b>Wire Strippers - 30AWG (Hakko)</b>
      <br />
      TOL-12630
    </a>
<!-- ----------WHITE SPACE BETWEEN PRODUCTS---------- -->
-   <a href="https://www.sparkfun.com/products/11952">
      <figure markdown>
        Flush Cutters - Hakko
      </figure>
    </a>

    ---

    <a href="https://www.sparkfun.com/products/11952">
      <b>Flush Cutters - Hakko</b>
      <br />
      TOL-11952
    </a>
<!-- ----------WHITE SPACE BETWEEN PRODUCTS---------- -->
-   <a href="https://www.sparkfun.com/products/12966">
      <figure markdown>
        Digital Multimeter - Basic
      </figure>
    </a>

    ---

    <a href="https://www.sparkfun.com/products/12966">
      <b>Digital Multimeter - Basic</b>
      <br />
      TOL-12966
    </a>
<!-- ----------WHITE SPACE BETWEEN PRODUCTS---------- -->
</div>

### Prototyping Accessories  _(Optional)_

Depending on your setup, you may want to use IC hooks for a temporary connection. However, you will want to solder header pins to connect devices to the plated through holes for a secure connection.

<div class="grid cards col-4" markdown>

-   <a href="https://www.sparkfun.com/products/12002">
      <figure markdown>
        Breadboard - Self-Adhesive (White)
      </figure>
    </a>

    ---

    <a href="https://www.sparkfun.com/products/12002">
      <b>Breadboard - Self-Adhesive (White)</b>
      <br />
      PRT-12002
    </a>
<!-- ----------WHITE SPACE BETWEEN PRODUCTS---------- -->
-   <a href="https://www.sparkfun.com/products/9741">
      <figure markdown>
        IC Hook with Pigtail
      </figure>
    </a>

    ---

    <a href="https://www.sparkfun.com/products/9741">
      <b>IC Hook with Pigtail</b>
      <br>
      CAB-09741
    </a>
<!-- ----------WHITE SPACE BETWEEN PRODUCTS---------- -->
-   <a href="https://www.sparkfun.com/products/553">
      <figure markdown>
        Break Away Male Headers - Right Angle
      </figure>
    </a>

    ---

    <a href="https://www.sparkfun.com/products/553">
      <b>Break Away Male Headers - Right Angle</b>
      <br />
      PRT-00553
    </a>
<!-- ----------WHITE SPACE BETWEEN PRODUCTS---------- -->
-   <a href="https://www.sparkfun.com/products/115">
      <figure markdown>
        Female Headers
      </figure>
    </a>

    ---

    <a href="https://www.sparkfun.com/products/115">
      <b>Female Headers</b>
      <br />
      PRT-00115
    </a>
<!-- ----------WHITE SPACE BETWEEN PRODUCTS---------- -->
-   <a href="https://www.sparkfun.com/products/8431">
      <figure markdown>
        Jumper Wires Premium 6
      <br />
      PRT-08431
    </a>
<!-- ----------WHITE SPACE BETWEEN PRODUCTS---------- -->
-   <a href="https://www.sparkfun.com/products/9140">
      <figure markdown>
        Jumper Wires Premium 6
      <br />
      PRT-09140
    </a>
<!-- ----------WHITE SPACE BETWEEN PRODUCTS---------- -->
</div>

### Suggested Reading

If you aren't familiar with the Qwiic Connection System, we recommend reading [here for an overview](https://www.sparkfun.com/qwiic).

<div style="text-align: center">
  <table style="border-style:none">
    <tr>
     <td style="text-align: center; vertical-align: middle;">
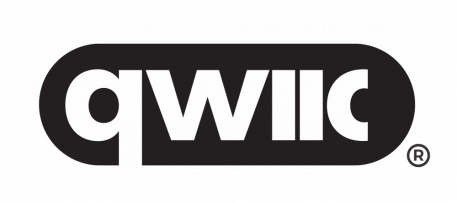
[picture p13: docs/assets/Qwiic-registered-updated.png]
Qwiic Connection System Click to learn more about the Qwiic Connection System!
     <div style="text-align: center">
     </div>
    </td>
    </tr>
    <tr>
      <td style="text-align: center; vertical-align: middle;"><div style="text-align: center"><i><a href="https://www.sparkfun.com/qwiic">Qwiic Connection System</a></i></div></td>
    </tr>
  </table>
</div>

If you aren’t familiar with the following concepts, we also recommend checking out a few of these tutorials before continuing.

<div class="grid cards col-4" markdown>
<!-- ----------WHITE SPACE BETWEEN GRID CARDS---------- -->
-   <a href="https://learn.sparkfun.com/tutorials/how-to-solder-through-hole-soldering">
      <figure markdown>
        How to Solder: Through-Hole Soldering
      </figure>
    </a>

    ---

    <a href="https://learn.sparkfun.com/tutorials/how-to-solder-through-hole-soldering">
      <b>How to Solder: Through-Hole Soldering</b>
    </a>
<!-- ----------WHITE SPACE BETWEEN GRID CARDS---------- -->
-   <a href="https://learn.sparkfun.com/tutorials/installing-arduino-ide">
      <figure markdown>
        Installing Arduino IDE
      </figure>
    </a>

    ---

    <a href="https://learn.sparkfun.com/tutorials/installing-arduino-ide">
      <b>Installing Arduino IDE</b>
    </a>
<!-- ----------WHITE SPACE BETWEEN GRID CARDS---------- -->
-   <a href="https://learn.sparkfun.com/tutorials/esp32-thing-plus-usb-c-hookup-guide">
      <figure markdown>
        ESP32 Thing Plus (USB-C) Hookup Guide
      </figure>
    </a>

    ---

    <a href="https://learn.sparkfun.com/tutorials/esp32-thing-plus-usb-c-hookup-guide">
      <b>ESP32 Thing Plus (USB-C) Hookup Guide</b>
    </a>
<!-- ----------WHITE SPACE BETWEEN GRID CARDS---------- -->
-   <a href="https://learn.sparkfun.com/tutorials/installing-board-definitions-in-the-arduino-ide">
      <figure markdown>
        Installing Board Definitions in the Arduino IDE
      </figure>
    </a>

    ---

    <a href="https://learn.sparkfun.com/tutorials/installing-board-definitions-in-the-arduino-ide">
      <b>Installing Board Definitions in the Arduino IDE</b>
    </a>
<!-- ----------WHITE SPACE BETWEEN GRID CARDS---------- -->
-   <a href="https://learn.sparkfun.com/tutorials/how-to-install-ch340-drivers/all">
      <figure markdown>
        How to Install CH340 Drivers
      </figure>
    </a>

    ---

    <a href="https://learn.sparkfun.com/tutorials/how-to-install-ch340-drivers/all">
      <b>How to Install CH340 Drivers</b>
    </a>
<!-- ----------WHITE SPACE BETWEEN GRID CARDS---------- -->
-   <a href="https://learn.sparkfun.com/tutorials/serial-peripheral-interface-spi">
      <figure markdown>
        Serial Peripheral Interface (SPI)
      </figure>
    </a>

    ---

    <a href="https://learn.sparkfun.com/tutorials/serial-peripheral-interface-spi">
      <b>Serial Peripheral Interface (SPI)</b>
    </a>
<!-- ----------WHITE SPACE BETWEEN GRID CARDS---------- -->
-   <a href="https://learn.sparkfun.com/tutorials/logic-levels">
      <figure markdown>
        Logic Levels
      </figure>
    </a>

    ---

    <a href="https://learn.sparkfun.com/tutorials/logic-levels">
      <b>Logic Levels</b>
    </a>
<!-- ----------WHITE SPACE BETWEEN GRID CARDS---------- -->
</div>

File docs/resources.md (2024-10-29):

Now that you've successfully got your SparkFun Qwiic Power Switch up and running, it's time to incorporate it into your own project! For more information, check out the resources below:

* [Schematic (PDF)](../assets/board_files/Qwiic_Power_Switch_Schematic_v10.pdf)
* [Eagle Files (ZIP)](../assets/board_files/Qwiic_Power_Switch_V10.zip)
* [Board Dimensions (PNG)](../assets/img/SparkFun_Qwiic_Power_Switch_Board_Dimensions.png)
* Component Datasheets
    * [PCA9536 4-Bit I<sup>2</sup>C and SMBus I/O Expander (PDF)](../assets/component_documentation/pca9536.pdf)
      * [PCA9306 Dual Bidirectional I<sup>2</sup>C Bus and SMBus Voltage-Level Translator (PDF)](../assets/component_documentation/pca9306.pdf)
    * [DMG2305UX P-Channel MOSFET (PDF)](../assets/component_documentation/DMG2305UX.pdf)
* [Arduino Library](https://github.com/sparkfun/SparkFun_Qwiic_Power_Switch_Arduino_Library)
* [GitHub Hardware Repo](https://github.com/sparkfun/Qwiic_Power_Switch)

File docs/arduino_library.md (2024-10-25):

!!! arduino
    This example assumes you are using the latest version of the Arduino IDE on your desktop. If this is your first time using Arduino IDE, library, or board add-on, please review the following tutorials.

    - [Installing the Arduino IDE](https://learn.sparkfun.com/tutorials/installing-arduino-ide)
    - [Installing an Arduino Library](https://learn.sparkfun.com/tutorials/installing-an-arduino-library)
    - [Installing Board Definitions in the Arduino IDE](https://learn.sparkfun.com/tutorials/installing-board-definitions-in-the-arduino-ide)

!!! note
    If you've never connected an CH340 device to your computer before, you may need to install drivers for the USB-to-serial converter. Check out our section on "[How to Install CH340 Drivers](https://learn.sparkfun.com/tutorials/how-to-install-ch340-drivers)" for help with the installation.

    - [How to Install CH340 Drivers](https://learn.sparkfun.com/tutorials/how-to-install-ch340-drivers/all)

SparkFun has written a library to work with the Qwiic Power Switch. You can obtain this library through the Arduino Library Manager by searching for "**SparkFun Qwiic Power Switch**". Find the one written by SparkFun Electronics and install the latest version. Users who prefer to manually install the library can get it from the [GitHub Repository](https://github.com/sparkfun/SparkFun_Qwiic_Power_Switch_Arduino_Library) or download the .ZIP by clicking the button below:

<div style="text-align: center"><a href="https://github.com/sparkfun/SparkFun_Qwiic_Power_Switch_Arduino_Library/archive/refs/heads/master.zip" class="md-button">SparkFun Qwiic Power Switch Arduino Library (ZIP)</a></div>

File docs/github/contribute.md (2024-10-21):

# Contribute: Help Fix our Mistake!
Spot something wrong? Feel free to contribute our open-source design and documentation. 

## Improve our Documentation
All of this documentation can be modified by you! Please help us make it better.

* These pages are contained in the [`docs` folder of the SparkFun Qwiic Power Switch repository](https://github.com/sparkfun/SparkFun_Qwiic_Power_Switch/tree/main/docs).

### Submit a Correction
1. Fork this repo
2. Add your corrections or improvements to the markdown file
3. File a pull request with your changes, and enjoy making the ~~words~~ ~~worlds~~ world a better place.
    * Once received, the documentation specialist will automatically be notified.
    * We will review your suggested improvements to make sure they are correct and fit within our documentation standards.

## Improve our Hardware Design
All of our designs are open-source! Please help us make it better.

* Our board design files are contained in the [`Hardware` folder of the SparkFun Qwiic Power Switch repository](https://github.com/sparkfun/SparkFun_Qwiic_Power_Switch/tree/main/Hardware).

### Submit a Design Improvement
1. Fork this repo
2. Add your design improvements
3. File a pull request with your changes, and enjoy making the ~~words~~ ~~worlds~~ world a better place.
    * Once received, the engineer in charge of the original design will automatically be notified.
    * We will review your suggested improvements, if they are within our board design standards and meet our product design requirements, we will flag these changes for our next board revision. *(Please note, that even if your suggestion is accepted, these changes may not be immediate. We may have to cycle through our current product inventory first.)*

## Contributors
Let's provided some recognition to the contributors for this project!

GitHub Contributors Image
<br>


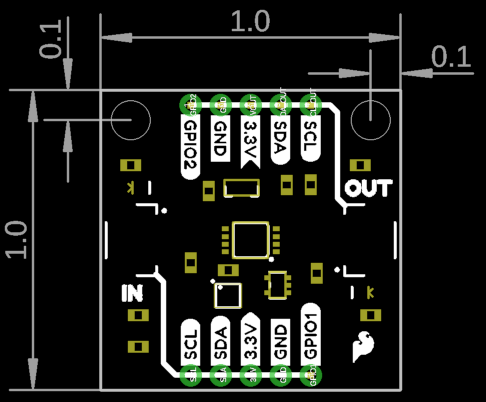
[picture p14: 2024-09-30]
img/Dimensions.png

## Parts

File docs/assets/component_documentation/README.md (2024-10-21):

SparkFun Documentation
=======================

This directory should include any necessary datasheets, example number crunching, etc.

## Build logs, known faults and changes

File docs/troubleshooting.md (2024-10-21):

### General Troubleshooting Help

!!! note
    <span class="glyphicon glyphicon-question-sign" aria-hidden="true"></span>
        <strong> Not working as expected and need help? </strong> <br /><br />

    If you need technical assistance and more information on a product that is not working as you expected, we recommend heading on over to the <a href="https://www.sparkfun.com/technical_assistance">SparkFun Technical Assistance</a> page for some initial troubleshooting. <br /><br />

    <div style="text-align: center"><a href="https://www.sparkfun.com/technical_assistance" target="sfe_technical_assistance" class="md-button">SparkFun Technical Assistance Page</a></div>

    If you don't find what you need there, the <a href="https://community.sparkfun.com/">SparkFun Forums</a> are a great place to find and ask for help. If this is your first visit, you'll need to create a forum account to search product forums and post questions.<br /><br />

    <div style="text-align: center"><a href="https://community.sparkfun.com/" class="md-button md-button--primary">Log Into SparkFun Forums</a></div>

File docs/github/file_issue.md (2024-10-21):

# Did we make a mistake?

Spot something wrong? Please let us know. 

!!! attention
    This is not where customers should seek assistance on a product. If you require technical assistance or have questions about a product that is not working as expected, please head over to the [SparkFun Technical Assistance](https://www.sparkfun.com/technical_assistance) page for some initial troubleshooting.
    <center>
    [SparkFun Technical Assistance Page](https://www.sparkfun.com/technical_assistance){ .md-button .md-button--primary }
    </center>

    If you can't find what you need there, you'll need a [Forum Account](https://forum.sparkfun.com/ucp.php?mode=register) to search product forums and post questions.

## Discrepancies in the Documentation

All of this documentation can be modified by you! Please help us make it better.

* The documentation files for these pages are contained in the [`docs` folder of the SparkFun Qwiic Power Switch repository](https://github.com/sparkfun/SparkFun_Qwiic_Power_Switch/tree/main/docs).

### Spot something wrong?
If a section of the documentation is incorrect, please [open an issue](https://github.com/sparkfun/SparkFun_Qwiic_Power_Switch/issues) and let us know.

### Do you have a suggested correction?
1. With a GitHub account, fork this repo
2. Add your correction(s) or improvement(s) to the markdown file(s)
3. File a pull request with your changes, and enjoy making the ~~words~~ ~~worlds~~ world a better place.
    * Once received, the documentation specialist will automatically be notified.
    * We will review your suggested improvement(s) to make sure they are correct and fit within our documentation standards.

## Problems in the Hardware Design

All of our designs are open-source! Please help us make it better.

* Our board design files are contained in the [`Hardware` folder of the SparkFun Qwiic Power Switch repository](https://github.com/sparkfun/SparkFun_Qwiic_Power_Switch/tree/main/Hardware).

### Does something not make sense?
If part of the design is confusing, please [open an issue](https://github.com/sparkfun/SparkFun_Qwiic_Power_Switch/issues) and let us know.

### Did we forget to include an important function of the board?
* Please keep in mind that we may intentionally exclude certain functions of the board to meet our product design requirements. *(For example, our Qwiic Micro boards are intended to fit on a small board layout and only use I<sup>2</sup>C communication; therefore, we may not have the SPI and interrupt pins available for users.)*
* If part of the board's functionality is missing, please [open an issue](https://github.com/sparkfun/SparkFun_Qwiic_Power_Switch/issues) and file a feature request.

### Do you wish to contribute directly to improving the board design?
1. With a GitHub account, Fork this repo
2. Add your design improvement(s)
3. File a pull request with your changes, and enjoy making the ~~words~~ ~~worlds~~ world a better place.
    * Once received, the engineer in charge of the original design will automatically be notified.
    * We will review your suggested improvement(s), if they are within our board design standards and meet our product design requirements, we will flag these changes for our next board revision. *(Please note, that even if your suggestion is accepted, these changes may not be immediate. We may have to cycle through our current product inventory first.)*

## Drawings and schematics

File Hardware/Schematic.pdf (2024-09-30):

## PCA9536 4-Bit GPIO

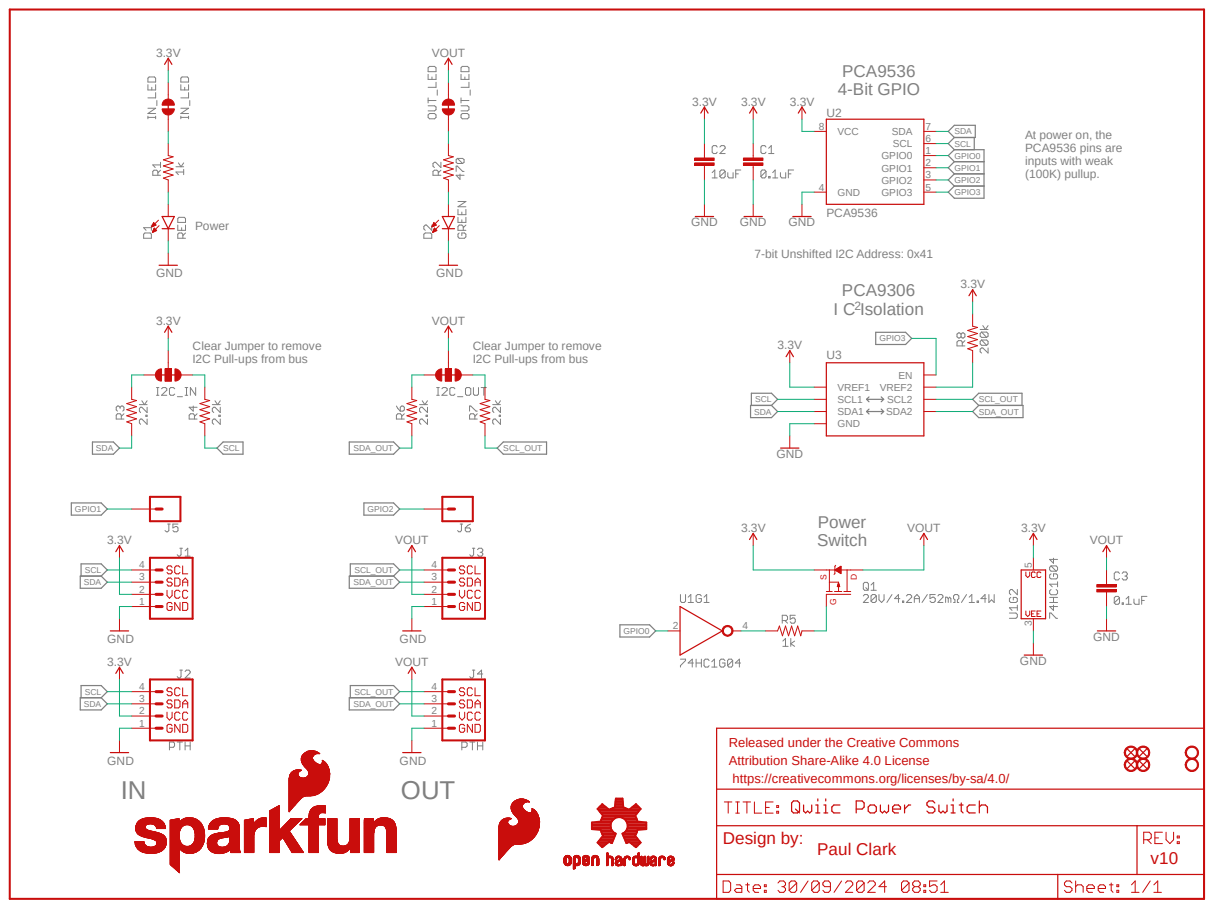
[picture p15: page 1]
Power; OUT; PCA9306 I C Isolation ²; Power Switch; GND; PCA9536; VOUT; GND 4; VCC 8; SDA; 7 SCL; 6 GPIO0; 1 GPIO1; 2 GPIO2; 3 GPIO3; SDA1 SCL1; VREF1 VREF2 SCL2 SDA2 GND; SCL; SCL SCL; GPIO0; GPIO1; GPIO2; GPIO2 SDA_OUT; SDA_OUT; SCL_OUT; SCL_OUT GPIO3 GPIO3; Paul Clark; Design by:

At power on, the
PCA9536 pins are
inputs with weak
(100K) pullup.

7-bit Unshifted I2C Address: 0x41

Clear Jumper to remove
I2C Pull-ups from bus

Released under the Creative Commons
Attribution Share-Alike 4.0 License
https://creativecommons.org/licenses/by-sa/4.0/

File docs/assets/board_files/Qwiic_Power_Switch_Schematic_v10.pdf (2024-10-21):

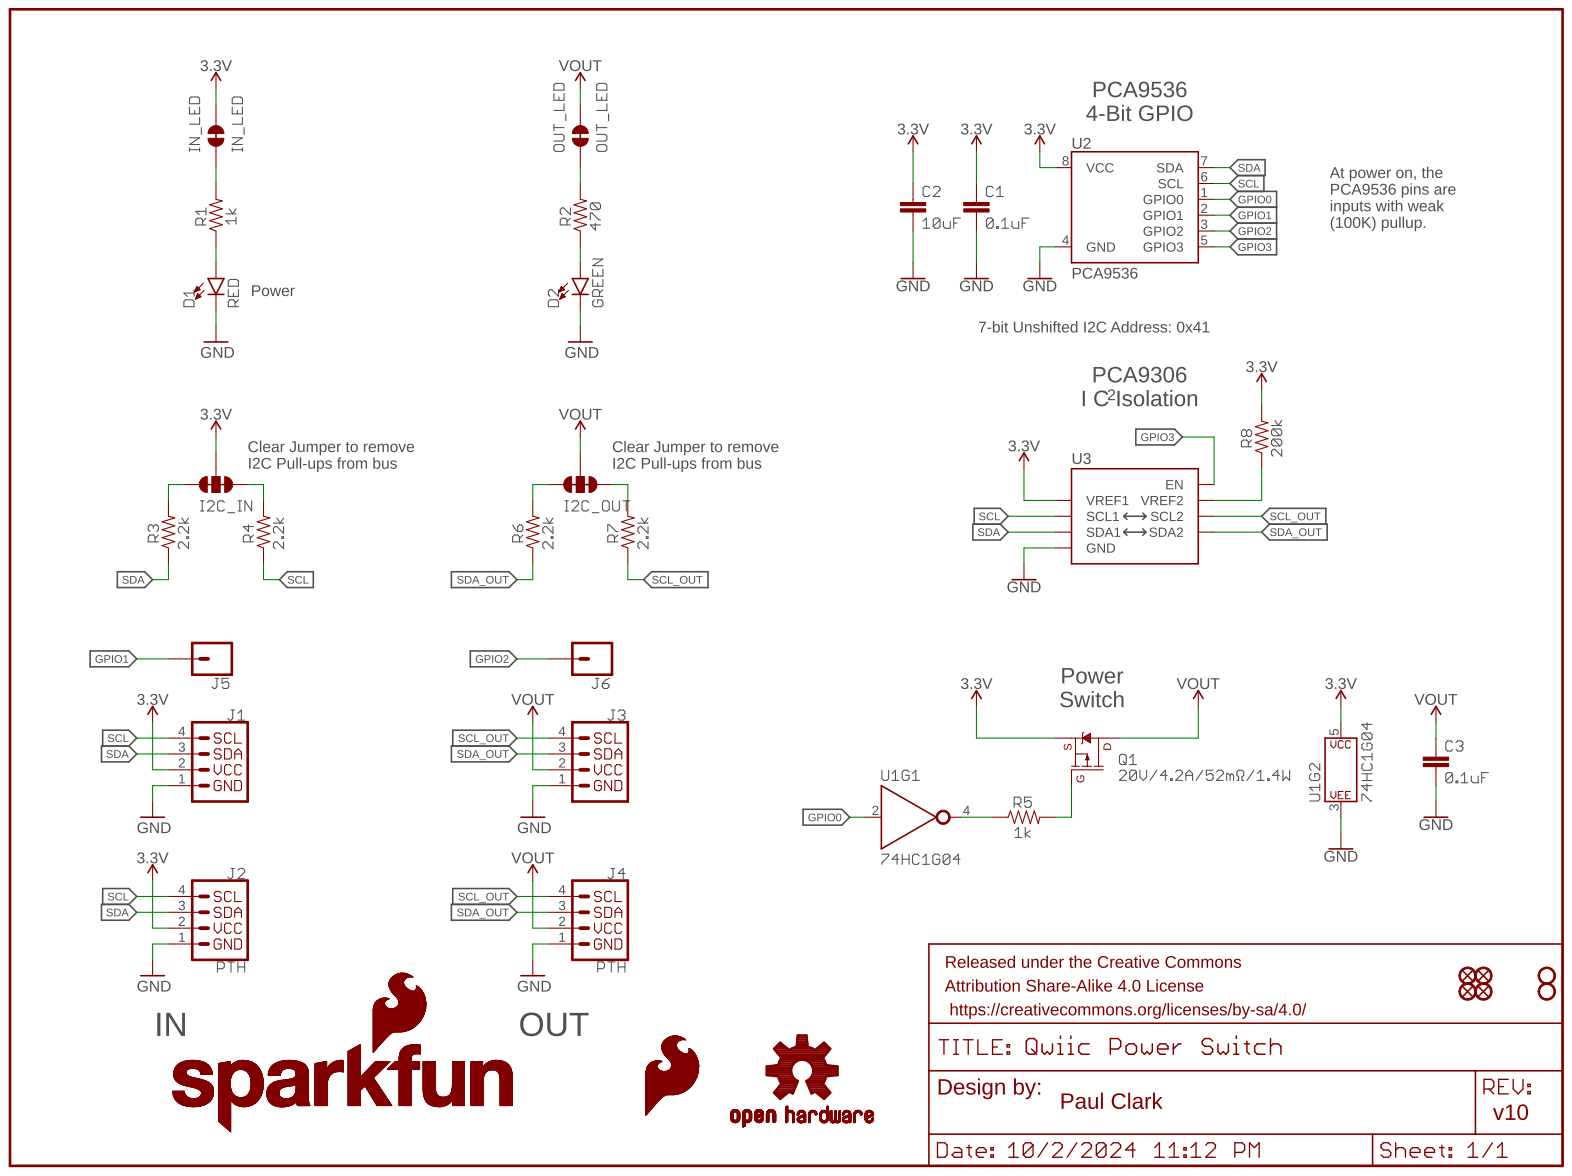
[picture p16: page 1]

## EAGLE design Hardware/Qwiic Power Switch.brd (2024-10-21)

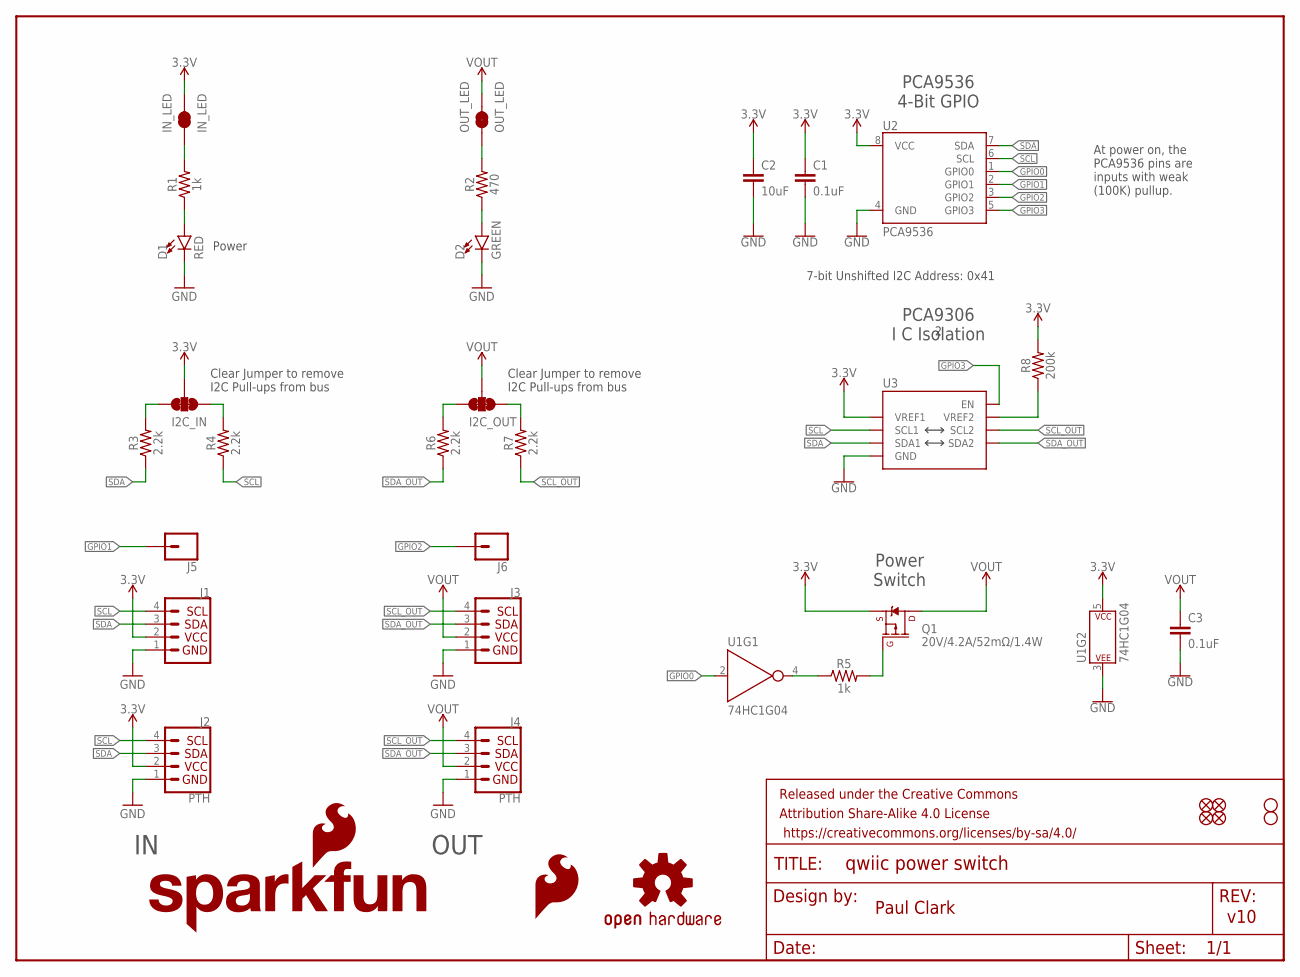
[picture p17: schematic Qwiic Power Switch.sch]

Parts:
C1, C3: 0.1uF; 0603
C2: 10uF; 0603
D1: RED; LED-0603
D2: GREEN; LED-0603
FRAME1: FRAME-LETTER; CREATIVE_COMMONS
I2C_IN, I2C_OUT: JUMPER-SMT_3_2-NC_TRACE_SILK; SMT-JUMPER_3_2-NC_TRACE_SILK
IN_LED: IN_LED; SMT-JUMPER_2_NC_TRACE_SILK
J1, J3: Qwiic Right Angle; JST04_1MM_RA
J2, J4: PTH; 1X04_NO_SILK
J5, J6: CONN_01PTH_NO_SILK_YES_STOP; 1X01_NO_SILK
JP1, JP2, JP5, JP6: FIDUCIAL1X2; FIDUCIAL-1X2
JP3, JP4: STAND-OFF
LOGO1: OSHW-LOGOMINI; OSHW-LOGO-MINI
LOGO2: SFE_LOGO_FLAME.1_INCH; SFE_LOGO_FLAME_.1
LOGO3: SFE_LOGO_NAME_FLAME.1_INCH; SFE_LOGO_NAME_FLAME_.1
OUT_LED: OUT_LED; SMT-JUMPER_2_NC_TRACE_SILK
Q1: 20V/4.2A/52mΩ/1.4W; SOT23-3
R1, R5: 1k; 0603
R2: 470; 0603
R3, R4, R6, R7: 2.2k; 0603
R8: 200k; 0603
U1: 74HC1G04; SOT353
U2: PCA9536; MSOP8
U3: PCA9306VSSOP_8PIN; VSSOP_8PIN

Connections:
3.3V: C1.1, C2.1, I2C_IN.2, IN_LED.2, J1.2, J2.2, Q1.2 (S), R8.2, U1.5 (P$V+), U2.8 (VCC), U3.P2 (VREF1)
GND: C1.2, C2.2, C3.2, D1.C, D2.C, J1.1, J2.1, J3.1, J4.1, U1.3 (P$V-), U2.4 (GND), U3.P1 (GND)
GPIO0: U1.2 (A), U2.1 (GPIO0)
GPIO1: J5.1, U2.2 (GPIO1)
GPIO2: J6.1, U2.3 (GPIO2)
GPIO3: U2.5 (GPIO3), U3.P8 (EN)
unnamed: I2C_IN.1, R4.2
unnamed: I2C_IN.3, R3.2
unnamed: D1.A, R1.1
unnamed: IN_LED.1, R1.2
unnamed: R5.1, U1.4 (Y)
unnamed: Q1.1 (G), R5.2
unnamed: OUT_LED.1, R2.2
unnamed: I2C_OUT.1, R7.2
unnamed: D2.A, R2.1
unnamed: I2C_OUT.3, R6.2
unnamed: R8.1, U3.P7 (VREF2)
SCL: J1.4, J2.4, R4.1, U2.6 (SCL), U3.P3 (SCL1)
SCL_OUT: J3.4, J4.4, R7.1, U3.P6 (SCL2)
SDA: J1.3, J2.3, R3.1, U2.7 (SDA), U3.P4 (SDA1)
SDA_OUT: J3.3, J4.3, R6.1, U3.P5 (SDA2)
VOUT: C3.1, I2C_OUT.2, J3.2, J4.2, OUT_LED.2, Q1.3 (D)

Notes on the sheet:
Paul Clark
v10
Clear Jumper to remove I2C Pull-ups from bus
Power
7-bit Unshifted I2C Address: 0x41
OUT
At power on, the PCA9536 pins are inputs with weak (100K) pullup.
PCA9536 4-Bit GPIO
PCA9306 I C Isolation
Power Switch

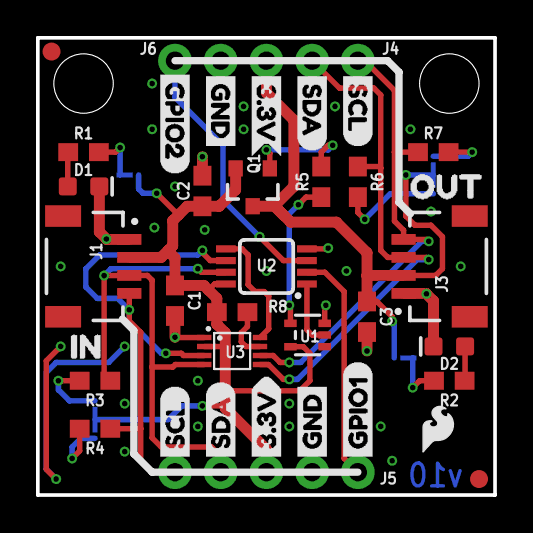
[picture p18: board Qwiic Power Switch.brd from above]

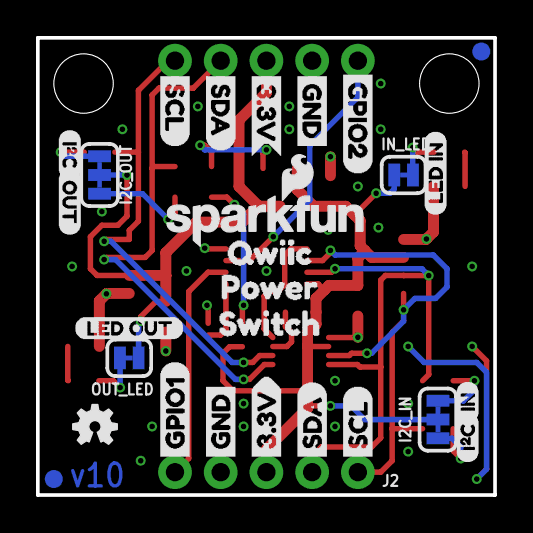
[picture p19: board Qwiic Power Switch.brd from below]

Board: 2 copper layers, 25.4 x 25.4 mm, 68 parts (28 on the bottom side), 22 nets.

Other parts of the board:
U$1, U$28: IN0
U$3, U$8, U$13, U$22: GND1
U$4, U$7, U$12, U$23: 3#3V0
U$5, U$11, U$15, U$27: SDA8
U$6, U$9, U$17, U$26: SCL9
U$10, U$18: I_SUPER2_C-()-03
U$14, U$31: OUT0
U$16, U$24: GPIO10
U$19: QWIIC0
U$20, U$25: GPIO20
U$29: LED_IN0
U$30: LED_OUT0
U$32: POWER0
U$34: SWITCH0

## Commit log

2024-10-21 Update Qwiic Power Switch.brd
    - Add Attribution
    - Add Measurement Units
    [Qwiic Power Switch.brd]
2024-10-21 Add Images, Intro, Hardware Overview, Arduino Library, Resources, Board Files
2024-10-29 Add MOSFET Datasheet
2024-10-31 Add GIF in Arduino Example

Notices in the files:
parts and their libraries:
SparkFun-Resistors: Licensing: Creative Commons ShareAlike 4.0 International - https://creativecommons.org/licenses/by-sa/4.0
